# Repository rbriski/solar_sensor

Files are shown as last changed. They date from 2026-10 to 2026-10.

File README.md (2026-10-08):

# Solar roof temperature sensor

A solar-powered **Seeed XIAO ESP32-C6** reads a waterproof DS18B20 probe, sends a reading over Wi-Fi, then sleeps. A separate Linux receiver stores readings and serves a live dashboard. This repository contains the wiring, firmware, receiver, perfboard layout and printable enclosure needed to reproduce the build.

The original unit is assembled and mounted. The current tray and probe arm have been physically fitted. Outdoor lifetime, sealing and battery endurance depend on the installation; the printed enclosure has no certified IP rating.

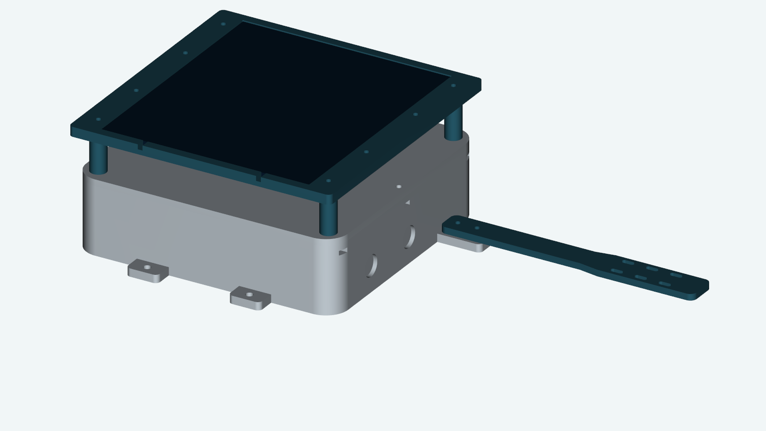
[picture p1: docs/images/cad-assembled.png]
Assembled enclosure and solar panel


## How it works

```mermaid
flowchart LR
    Panel[5 V solar panel] --> Manager[DFRobot DFR0559]
    Battery[Single-cell lithium battery] <--> Manager
    Manager -->|USB power| C6[XIAO ESP32-C6]
    Probe[DS18B20 probe] -->|D2| C6
    C6 -->|Wi-Fi / authenticated HTTPS| Receiver[Linux receiver]
    Receiver --> DB[(SQLite)]
    Receiver --> Dashboard[Private live dashboard]
    Receiver -. optional MQTT .-> Consumer[Pi or other consumer]
```

The sensor can use an isolated device Wi-Fi network. Tailscale Funnel gives it an HTTPS route to the receiver without joining the tailnet. The receiver can run on a DGX, spare Linux computer or server; a Pi or pool controller can consume its data independently. The sensor does not depend on chlorination, flow-control software or a running Pi.

Default firmware sleeps for **300 seconds**, with at most 20 seconds awake per cycle. It verifies TLS and requires an acknowledgement after the receiver saves the event. Network failures lead to sleep and a fresh reading next wake; the node does not buffer missed readings. Retried events keep their original receipt time.

## Build it in this order

| Step | Guide | Completion check |
| --- | --- | --- |
| 1 | [Parts and tools](docs/parts.md) | Correct C6, power manager and measured component sizes |
| 2 | [Breadboard wiring](docs/wiring.md) and [USB probe firmware](docs/firmware.md#1-test-the-probe-over-usb) | A valid temperature changes when you warm the probe |
| 3 | [Receiver setup](monitor/README.md) and [wireless firmware](docs/firmware.md#2-build-the-wireless-firmware) | A new reading appears on the dashboard |
| 4 | [Battery and solar power](docs/wiring.md#battery-and-solar-power) | Readings continue on solar-manager USB power |
| 5 | [Perfboard layout](docs/perfboard/README.md) | Continuity and powered voltage checks pass |
| 6 | [Print and assemble](hardware/enclosure/README.md) | Parts fit, cables seal and readings continue after closing |
| 7 | Choose a mount for your location | Probe position, radio reception and attachment suit the site |

The [full schematic](docs/perfboard/full-schematic.svg) and perfboard views render on GitHub. Download the [complete Bambu X2D project](hardware/enclosure/bambu/solar-enclosure-X2D.3mf) or use the [STEP/STL models](hardware/enclosure/models) for another printer.

**Optional battery voltage:** the divider works while the C6 is powered, but is not automatically isolated when that power disappears. Leave its jumper open for the basic unattended build. Read the [battery-sense limits](docs/wiring.md#optional-battery-voltage) before adding it. Voltage is not a calibrated charge percentage.

## Find your way around

- [Troubleshooting](docs/troubleshooting.md): temperature, power and HTTPS faults.
- [Reproducing and changing the project](CONTRIBUTING.md): AI-agent starting prompt, source files and checks.
- [Optional mounting example](hardware/mount-example/README.md): a clamp mount for one roof structure. Another mount can use the enclosure's external ears.
- `firmware/`: USB test and sleeping Wi-Fi node; local credentials are ignored.
- `monitor/`: receiver, dashboard, transport checks and systemd installer.
- `hardware/enclosure/`: current CAD, models, settings and assembly instructions.

Start with the C6 build as documented. A different board, battery, adapter, perfboard hole pattern or panel can require wiring and CAD changes. Confirm differences before printing or soldering.

## License

The original code, documentation and CAD designs are available under the [MIT License](LICENSE), copyright © 2026 Bob Briski. Bundled third-party material retains its own terms; see [third-party notices](THIRD_PARTY_NOTICES.md).

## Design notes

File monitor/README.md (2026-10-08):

# Linux receiver and dashboard

[Build overview](../README.md) · [Firmware next](../docs/firmware.md)

The receiver accepts token-authenticated HTTPS readings through **Tailscale Funnel**, saves them in SQLite, then acknowledges the event ID. It writes a dashboard snapshot every two seconds. A Pi or another consumer can read the receiver's data independently; MQTT is optional.

This setup needs Linux with systemd user services, Python 3.10+, and [Tailscale](https://tailscale.com/download/linux) signed in to your tailnet. Use an always-on receiver. The ESP32 does **not** run Tailscale: it reaches the public Funnel hostname from ordinary Wi-Fi. That network must allow DNS, NTP and the selected HTTPS port.

## 1. Install the receiver

Clone the repository to a permanent directory and run from its root:

```bash
python3 -m venv .venv
.venv/bin/python -m pip install -r monitor/requirements.txt
.venv/bin/python monitor/install.py --public-url 'https://YOUR-RECEIVER.YOUR-TAILNET.ts.net:10000/solar-roof/ingest'
```

Replace the example hostname with this receiver's full Tailscale DNS name, visible in `tailscale status --json` under `Self.DNSName` (omit its final dot). Enable HTTPS certificates and Funnel for the node as required by your tailnet policy. The [Funnel setup guide](https://tailscale.com/docs/features/tailscale-funnel) describes those prerequisites.

The installer creates:

| Path | Contents |
| --- | --- |
| `~/.config/solar-sensor/collector.json` | Private token and receiver settings, mode 0600 |
| `~/.config/solar-sensor/transport-watchdog.env` | Public URL, snapshot path, recovery setting, mode 0600 |
| `~/.local/share/solar-sensor/readings.sqlite3` | Durable readings, created when the receiver runs |
| `~/.local/share/solar-sensor/public/` | Dashboard, latest JSON and public transport summary |
| `~/.config/systemd/user/solar-sensor-*` | User units with your actual repository/Python paths |

It generates a random `ingest_token` and **keeps existing credentials, data paths and recovery settings on reinstall**. Open `collector.json` locally to copy the token into the firmware's ignored `secrets.h`. Do not paste it into issue reports. Only HTML, JavaScript and public summaries belong in the `public` directory; keep the private config and database outside it.

The installer does not start services or change Tailscale. Run:

```bash
systemctl --user daemon-reload
systemctl --user enable --now solar-sensor-collector.service
systemctl --user status solar-sensor-collector.service --no-pager
sudo loginctl enable-linger "$USER"
```

Lingering lets the user services run after logout and start at boot. Keep the repository and virtual environment at their installed paths; rerun the installer if moving them.

## 2. Route public ingestion and private viewing

First inspect existing routes with `tailscale serve status` and `tailscale funnel status`. The example uses **10000 for public ingestion** and **8443 for private viewing**; choose unused ports if the receiver already hosts other services.

```bash
tailscale funnel --bg --https=10000 --set-path=/solar-roof http://127.0.0.1:8790
tailscale serve --bg --https=8443 http://127.0.0.1:8791
```

If Tailscale requires administrative permission, use your established operator account or run those configuration commands with `sudo`. Funnel supports ports 443, 8443 and 10000; its [CLI reference](https://tailscale.com/docs/reference/tailscale-cli/funnel) explains persistent `--bg` routes. **Keep the dashboard on a different port:** Funnel makes a host/port public, so another path on the same port is not a private dashboard.

The ingest server binds only to loopback and serves POST `/ingest` or `/solar-roof/ingest`; it does not serve files. The optional dashboard server binds to loopback on 8791. Default URLs:

```text
Sensor URL:  https://YOUR-RECEIVER.YOUR-TAILNET.ts.net:10000/solar-roof/ingest
Dashboard:   https://YOUR-RECEIVER.YOUR-TAILNET.ts.net:8443/
Data feed:   https://YOUR-RECEIVER.YOUR-TAILNET.ts.net:8443/latest.json
```

Check the public ingest route without a token. **401 Unauthorized is the expected healthy response**:

```bash
curl --silent --show-error --output /dev/null --write-out '%{http_code}\n' --request POST 'https://YOUR-RECEIVER.YOUR-TAILNET.ts.net:10000/solar-roof/ingest'
```

A browser GET returns 404 by design. View the dashboard from a tailnet-connected browser. After [uploading firmware](../docs/firmware.md), check the receipt time advances and persists after restarting the collector. Retransmission of the same event must not make an old reading look new.

## 3. Monitor transport health

```bash
systemctl --user enable --now solar-sensor-transport.timer
systemctl --user start solar-sensor-transport.service
journalctl --user -u solar-sensor-transport.service -n 20 --no-pager
```

The watchdog checks local ingestion, public DNS, Funnel routing and TLS through each public IPv4 address. It checks public DNS separately from MagicDNS so a healthy tailnet-only route cannot mask a broken public route. It combines transport results with reading age. A healthy route with an overdue sensor is a sensor/power problem, not a reason to reconnect Tailscale.

Automatic recovery defaults **off** for new installs. To enable it, allow the service user to operate Tailscale (for example, `sudo tailscale set --operator="$USER"` if appropriate for this host) and change this line in the private environment file:

```text
SOLAR_FUNNEL_AUTO_RECOVERY=1
```

The next timer run reads it. Recovery requires three consecutive qualifying failures, stale sensor data, a healthy local collector, two successful public DNS checks and failed public network/TLS transport. It excludes certificate-validation errors and ordinary HTTP authorization errors. It allows one reconnect per incident with a one-hour cooldown, and rearms after five healthy checks.

The recovery service briefly runs `tailscale down` then `tailscale up`; this affects **all Tailscale connections on that receiver**. It records a persistent recovery marker, checks preferences/routes afterward and includes an `ExecStopPost` recovery path. It does not reset Funnel configuration. Set the variable back to `0` to disable automatic reconnects while keeping monitoring. Existing installations retain their current opt-in on reinstall.

## Optional MQTT consumers

No broker is required for HTTPS ingestion or the dashboard. To relay readings, add these keys to the private collector config and restart its service:

```json
{
  "mqtt_enabled": true,
  "host": "127.0.0.1",
  "port": 1883,
  "username": "YOUR_BROKER_USER",
  "password": "YOUR_BROKER_PASSWORD"
}
```

These are additional keys, not a replacement for the full config. Use a local or appropriately secured broker; this example uses plain MQTT on loopback. Fresh events are relayed to `pool/solar-roof/temperature`, QoS 1, retained. The receiver also accepts legacy non-retained readings on that topic and acknowledges them on `pool/solar-roof/ack`. Retained MQTT messages are never treated as newly received samples.

MQTT failure does not prevent an HTTPS reading from being saved or acknowledged. MQTT relay is best effort, with no durable forwarding queue. Consumers needing a complete history should read SQLite or the receiver's snapshot instead of treating broker delivery as the system of record.

## Data and maintenance

`latest.json` contains `generated_at`, total `count`, `latest` and the latest 240 events in `history`, oldest first. Each event has receiver-generated `received_at`, the node's unique `event_id`, temperatures/status, Wi-Fi signal and sleep interval. Invalid probe temperatures and disabled/invalid battery voltage are null. Freshness uses receipt time, not value changes; a duplicate preserves its original timestamp.

SQLite table `readings` contains `event_id TEXT PRIMARY KEY`, `received_at REAL`, and the original JSON `payload`. The database keeps all events. Back it up with SQLite's backup command rather than copying a live database without its WAL:

```bash
sqlite3 "$HOME/.local/share/solar-sensor/readings.sqlite3" ".backup '/path/to/backup/readings.sqlite3'"
journalctl --user -u solar-sensor-collector.service -n 30 --no-pager
systemctl --user list-timers solar-sensor-transport.timer --no-pager
```

The dashboard keeps updating while the sensor sleeps; an overdue reading turns its status red. See [troubleshooting](../docs/troubleshooting.md) for power, probe and transport diagnosis. This receiver currently handles one sensor identity, `roof-solar-reference`; adding multiple nodes requires changes to identity validation and per-sensor dashboard storage/querying.

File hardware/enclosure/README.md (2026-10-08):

# Enclosure, printing and assembly

[Project overview](../../README.md) · [Parts](../../docs/parts.md) · [Optional mount](../mount-example/README.md)

This is the **current fitted set**: original body/lid/frame geometry, corrected four-corner perfboard tray and paired-slot probe arm. The full project contains these parts together. Old trays, edge clips and perpendicular-slot arms are no longer alternatives to choose between.

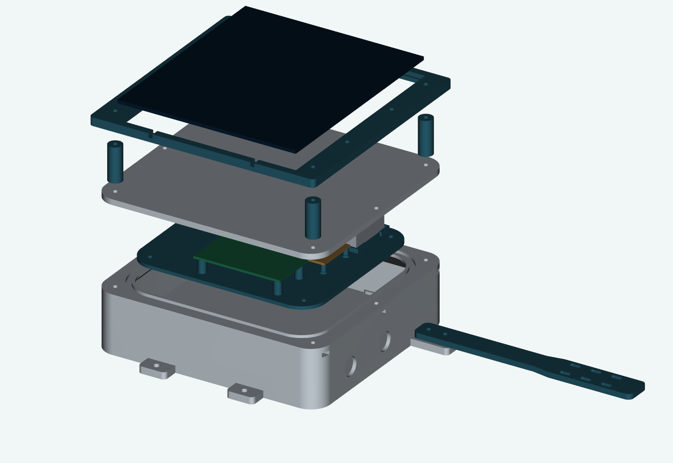
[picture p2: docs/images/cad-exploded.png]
Exploded assembly


## Files to print

Download [solar-enclosure-X2D.3mf](bambu/solar-enclosure-X2D.3mf) with GitHub's **Download raw file** button and open it in Bambu Studio. It contains **13 objects on four plates** with saved X2D printer, process and filament settings. Check the selected printer, nozzle and plate before sending a print.

| Plate | Parts | Quantity |
| --- | --- | --- |
| 1 | [Base](models/base.stl) | 1 |
| 2 | [Lid](models/lid.stl), [25 mm panel spacers](models/panel_spacer.stl) | 1 + 4 |
| 3 | [Solar panel frame](models/panel_frame.stl) | 1 |
| 4 | [Tray](models/tray.stl), [panel clips](models/panel_clip.stl), [probe arm](models/probe_arm.stl) | 1 + 4 + 1 |

All parts have editable STEP companions in [models](models). `assembly-reference.step` includes non-printable component envelopes for clearance checks; do not slice the whole reference assembly.

The saved settings use **Bambu X2D, standard 0.4 mm nozzle, Textured PEI**, white PETG at **240 °C**, bed **80 °C first layer / 75 °C thereafter**, 0.20 mm layers, 6 walls, 6 top/bottom layers, 25% gyroid, no supports and a 6 mm outer brim. Outer walls are 45 mm/s and volumetric flow is capped at 8 mm³/s. These follow the original filament label; adjust for a different material or calibrated printer.

The project is sliced and reopened with Bambu Studio 2.8.2.61 CLI. Its [validation record](bambu/project-validation.json) records settings, mesh checks and estimates. Plate thumbnails are rendered from the actual CAD because offscreen native thumbnails were unavailable. GUI interaction, seal performance and hot-weather strength are not certified by those checks.

## Dimensions that must match your parts

| Item | Modeled fit |
| --- | --- |
| Body | 164 × 152 × 42 mm, excluding external mounting ears; 2.4 mm walls, 3 mm floor |
| Solar panel | 130 × 150 × 2.5 mm; 130.8 × 150.8 mm pocket, central wire clearance |
| Battery | Actual measured pack 54 × 33 × 10 mm |
| Perfboard | 70 × 30 mm; **66 × 26 mm hole centers**; 1.5 mm board, 10 mm components above and 1 mm solder below |
| DFR0559 | 63 × 33 mm; **55 × 25 mm hole centers**; 1.6 mm board, 9 mm components above and 1 mm below |
| Cable bend allowance | 45 mm beyond the manager board's USB end |
| Glands | Two PG7 holes, 13.2 mm diameter through 2.4 mm wall |
| O-ring | AS568-164 EPDM 70A, 158.42 mm ID × 2.62 mm cross section |
| Groove | 3.8 mm wide, 2 mm deep; rounded rectangle, 144 × 132 mm centerline, 22 mm corner radius |
| External mounting ears | Four 4.5 mm holes on 64 × 164 mm centers |

Different generic perfboards often have different mounting holes even if both are sold as “3 × 7 cm.” Measure centers before printing. The current perfboard posts replace the earlier incorrect mount; the DFRobot and battery locations remain fitted.

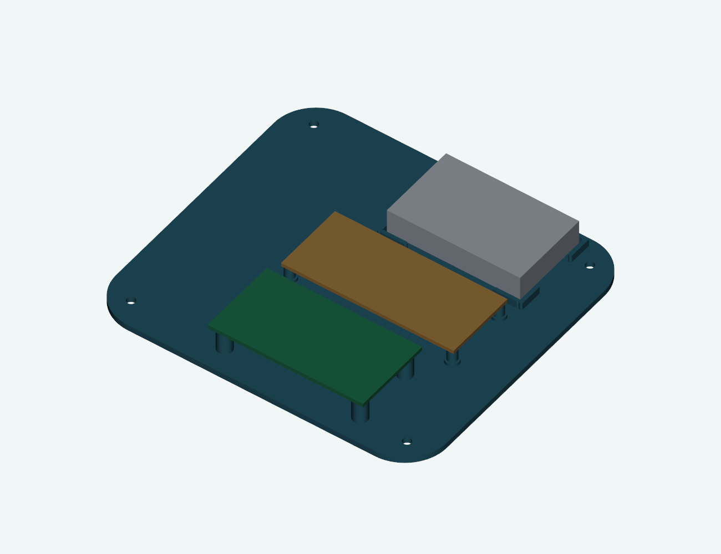
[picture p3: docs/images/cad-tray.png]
Tray with board and battery envelopes


Current perfboard mounting dimensions

## Fasteners

Lengths are measured **under the head**, including a pointed self-tapping screw's tip. Use small pan or button heads where they clear the components. Drive printed-plastic screws by hand. Self-tapping means they cut/form threads in the printed pilot; **self-drilling screws are not intended**.

| Quantity | Fastener | Joint | Type |
| --- | --- | --- | --- |
| 4 | **M1.7 × 6 mm** | C6 **perfboard** to tray posts | **Self-tapping for plastic**, no washer in the calculated stack |
| 4 | **M3 × 5 mm** | DFRobot to raised tray posts | **Self-tapping for plastic**, no washer in the calculated stack |
| 4 | **M3 × 6 mm** | Tray to body posts | **Self-tapping for plastic**, no washer in the calculated stack |
| 4 | **M3 × 45 mm** | Frame → spacer → lid → body corner nut | **Machine screw** + flat washer |
| 2 | **M3 × 12 mm** | Two middle side lid holes → body nuts | **Machine screw** + flat washer |
| 4 | **M3 × 10 mm** | Four panel retaining clips → frame nuts | **Machine screw** + flat washer |
| 2, optional | **M3 × 10 mm** | Probe arm → body bracket nuts | **Machine screw** + flat washer |
| 12, or 10 without arm | Ordinary M3 hex nuts | Six body closure pockets, four clip pockets, two arm pockets | Not nylon locknuts; pockets assume about 5.5 mm across flats / 2.4 mm thickness |
| 12, or 10 without arm | M3 flat washers, about 0.5 mm thick | Machine-screw joints above | Do not add to board/tray stacks without recalculating |

The original builder recalled **M1.7 self-tapping for the C6/perfboard** and **M3 self-tapping for DFRobot and tray**. The lengths above are derived from the CAD, not a guess at the installed screws:

| Joint | Material under screw head | Blind pilot depth | Screw insertion including point | Remaining tip clearance |
| --- | --- | --- | --- | --- |
| Perfboard, 6 mm screw | 1.5 mm board | 5.3 mm, Ø1.3 mm | 4.5 mm | **0.8 mm** |
| DFRobot, 5 mm screw | 1.6 mm board | 5.0 mm, Ø2.6 mm | 3.4 mm | **1.6 mm** |
| Tray, 6 mm screw | 2.4 mm tray | 4.0 mm, Ø2.6 mm | 3.6 mm | **0.4 mm** |

**The tray clearance is tight.** Check actual screw length, print thickness and pilot depth before tightening. A screw must clamp the part before its tip bottoms out. Self-tapping thread profiles vary; nominal diameter alone does not prove pilot compatibility. Check one post by hand, stop if the post cracks or the screw bottoms, and avoid an oversized head touching circuitry. The C6 itself is soldered to the perfboard; these four small screws secure the perfboard, not the C6 module.

## Assembly sequence

1. Remove brims and strings. Dry-fit gland nuts, ordinary M3 nuts and boards. Inspect screw pilots without enlarging them indiscriminately. Keep batteries away from tools and loose screws.
2. Install two glands with their supplied wall seals. Use **one round cable per gland**: probe and panel separately. Two cables under one ordinary round seal leave a potential leak path. Pass cables through before termination and make external drip loops.
3. Fasten DFRobot and perfboard to the tray using their self-tapping screws. Keep solder protrusions within the modeled 1 mm underside clearance. Strap the battery softly in its cradle; do not puncture or compress it.
4. Fit the tray with four M3 × 6 self-tapping screws. Route the short USB cable in its bend space; secure wiring away from lid, O-ring and fasteners. Complete the [power and reading checks](../../docs/perfboard/README.md#checks-before-power).
5. Fit the panel in the frame, rear toward the enclosure. Slide the **four panel clips** over its inactive edge and fasten with M3 × 10 machine screws and nuts. The frame ledge supports the panel; the clips keep it from lifting. They are not clamps for crushing the panel. Allow its rear wires to bend without pinching.
6. Fit the probe arm, if used, with two M3 × 10 machine screws and nuts. Pass ties through the paired longitudinal slots, around the probe and back through the matching slot. Keep the sensing end exposed and away from direct contact with the warm enclosure.
7. Lay the O-ring evenly in the clean lid groove. Install the lid, four 25 mm spacers and panel frame. The four **M3 × 45** screws pass through frame and spacers, through the lid and into ordinary nuts captured in the body. The two **M3 × 12** screws close the remaining middle side holes. Tighten evenly; stop when seated rather than distorting the lid.
8. Confirm a new remote reading after closing. Check seals with the electronics and battery removed before relying on the case outdoors; dry completely afterward. Monitor internal temperature against the battery maker's charge-temperature limit, especially in sun. A white case and panel shade do not guarantee safe battery temperature.

Panel retention and lid connection

Probe ties through paired slots

Probe placement depends on what you want to measure. This exposed probe is a solar reference, not a shielded meteorological air-temperature sensor. Keep its sensing end outside enclosure/panel shadow and avoid touching the case or mounting hardware. Compare positions at your site; there is no universal minimum cable distance. A different mount can attach to the external ears without opening the sealed volume.

## Rebuild the design

See [development commands](../../CONTRIBUTING.md#cad-and-print-project). `build_enclosure.py` exports current solids, meshes and clearance/fastener checks. Edit the relevant geometry functions for substitutions, regenerate, inspect fit and regenerate the print project together. The exported `parameters.json` describes dimensions; editing it alone does not change CAD.

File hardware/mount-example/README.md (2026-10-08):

# Optional clamp-mount example

[Enclosure](../enclosure/README.md) · [Project overview](../../README.md)

This is one installed solution for a particular existing roof collector structure. It attaches to dry rigid support tubes using lined saddles and worm-drive clamps, without changing the assembled enclosure. Treat it as a worked example for adapting the enclosure's external ears, not a universal shingle attachment.

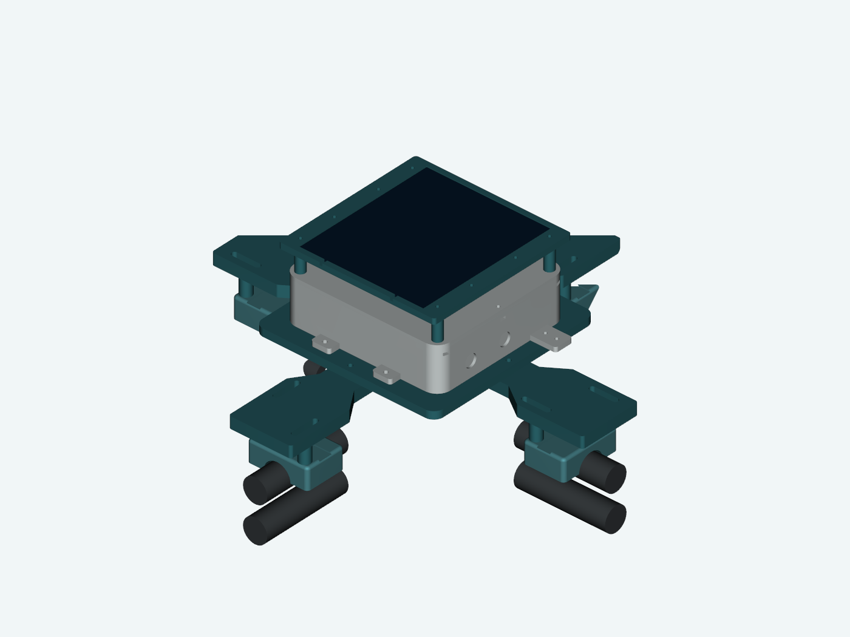
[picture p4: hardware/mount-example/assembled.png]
Example assembled clamp mount


The original measurements were approximately 25.4 mm tube diameter, 12.7 mm clear vertical gap between tubes, 73 mm square openings and 305 mm between opposite opening centers. Slots allow approximately 281–329 mm opposite spacing. The carrier accepts the enclosure's four holes on **64 × 164 mm centers**. Measure your structure and assess its condition/load capacity before reusing this design.

## Parts and fasteners

| Part | Quantity | Notes |
| --- | --- | --- |
| [Carrier](models/carrier.stl) | 1 | 190 mm square frame |
| [Arm](models/arm.stl) | 4 | 12 mm thick, slotted saddle connections |
| [Saddle](models/saddle.stl) | 4 | Current self-tapping version; 3.5 mm pilots, 20 mm blind depth |
| [20 mm spacer](models/spacer-20.stl) | 8 | 4.5 mm bore, 12 mm outside diameter |
| M4 × 20 mm machine screw | 4 | Enclosure ears to carrier; M4 washers and nylon locknuts |
| M4 × 25 mm machine screw | 8 | Arms to carrier; M4 washers and nylon locknuts |
| **#8 × 2 inch self-tapping screw** | 8 | Stainless pan head; fits existing spacers and arm slots |
| Large washers, approximately 12 mm OD, 1 mm thick | 8 | Under #8 screw heads, covering 6 mm slots |
| Stainless worm-drive clamps, 40–60 mm range, 9 mm band | 4 | One around each upper tube and saddle; head must fit the 14 mm channel |
| 1 mm EPDM lining | 4 strips | Between saddle/clamp and tube |

The selected screw example is [Everbilt #8 × 2 inch stainless pan-head self-tapping, model 807872](https://www.homedepot.com/p/204283146). A 50.8 mm screw through a 1 mm washer, 12 mm arm and 20 mm spacer enters the saddle by **17.8 mm**, leaving **2.2 mm** before the blind pilot floor. This includes the pointed tip, not all full-depth threads. Check actual screw and washer dimensions.

Use [replacement-saddles-X2D.3mf](replacement-saddles-X2D.3mf) for **four saddles only**, configured for the same white PETG/X2D setup as the enclosure. Its [mesh validation](project-validation.json) confirms the current saddle geometry. It does not contain carrier, arms or spacers; their current STEP/STL files are in [models](models). The supplied saddle STL is already rotated onto its axial end for printing. Do not print the assembly-reference meshes as extra parts.

## Installation order

1. Line and place each saddle over its **upper dry support tube**. Thread one worm clamp under that tube and through the saddle's crown channel. Do not wrap both tubes together. Tighten only enough to retain the saddle without damaging aged plastic.
2. Attach the four arms to the carrier, then the assembled enclosure to the carrier using the M4 machine screws and locknuts.
3. Set the assembly on the eight spacers. Insert #8 screws from above, through washers, arm slots and spacers into the saddle pilots. The spacers must be free clearance around the screws. Hand-tighten evenly; no inaccessible locknut is required below a saddle.
4. Check that neither screws nor clamps touch the lower tubes or roof, cables have slack and drip loops, the panel/probe have the intended exposure, and new readings still arrive.

Clamp routing

Self-tapping saddle stack

`build_mount.py` reproduces the current geometry using the enclosure's CAD helpers. The original unit is mounted, but there is no measured wind rating, hot-weather creep life or pull-out rating. Do not attach blindly to shingles, plumbing or an unknown roof component; choose and verify an attachment appropriate to the actual site.

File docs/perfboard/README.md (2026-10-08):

# Perfboard assembly

[Breadboard first](../wiring.md) · [Enclosure next](../../hardware/enclosure/README.md)

Use **30 × 70 mm isolated-pad board**, 10 columns across the short side and 24 rows along the long side. Numbers **1–10** run across; letters **A–X** run along. USB faces row A. These are hole coordinates, not GPIO numbers: hole **D2** happens to carry C6 signal **D2**, while A0 is at **B2**.

Full schematic

## Component side: insulated wires

Component side, USB at top

All solid top runs are **insulated wires connecting their two ends**. A bend over another pad is not a solder joint. The C6 header rows occupy B2–H2 and B8–H8. Its B8/5V pad is unused.

| Part | Holes | Detail |
| --- | --- | --- |
| R3, 4.7 kΩ | L2–L6 | Probe DATA pull-up to 3V3; omit the breadboard adapter |
| R1, 100 kΩ | P3–T3 | Optional BAT+ sense resistor |
| R2, 100 kΩ | P5–T5 | Optional sense-to-ground resistor |
| C1, 100 nF | P7–R7 | Optional sense filter; nonpolar |
| J1, two-pin header | V3–V4 | Optional removable sense shunt; leave open initially |
| TB1, 3-position terminal | W7, W8, W9 | **DATA, 3V3, GND**, respectively; cable openings face row X |
| BAT+ sense lead | X3 | Optional, from manager BAT IN +; not the main battery power lead |

| Insulated wire | Endpoints | Signal |
| --- | --- | --- |
| W1 | B1 → O3 | A0 sense, optional |
| W2 | D1 → K2 | DATA, kept clear of D3–D6 headers |
| W3 | D9 → K6 | 3V3 |
| W4 | L1 → U7 | DATA to terminal block |
| W5 | L7 → U8 | 3V3 to terminal block |

Keep enough clearance around USB and terminal screws. The 2.54 mm block fits this layout; a wider-pitch block needs a new layout.

## Solder side: bare bridges and shared ground

Solder side, mirrored with USB at top

This view is **mirrored left to right**, with USB still at the top. Columns now read 10–1. Do not turn the drawing upside down. Bare runs deliberately join intermediate pads on their listed paths; inspect them for accidental contact with adjacent pads.

| Run | Path |
| --- | --- |
| G0 | C8 → C10 → T10, shared ground rail |
| G1 | L9 → L10, spare ground landing |
| G2 | R7 → R10, capacitor ground |
| G3 | T5 → T10, resistor ground |
| G4 | T10 → W10 → W9, terminal ground |
| S1 | B1 → B2 |
| S2 | D1 → D2 |
| S3 | D8 → D9 |
| S5 | K2 → L2 → L1 |
| S6 | K6 → L6 → L7 |
| S9 | O3 → P3 |
| S10 | P3 → P7, including P5 |
| S12 | V4 → T4 → T3 |
| S14 | V3 → X3 |
| S15 | U7 → W7 |
| S16 | U8 → W8 |

For a temperature-only build omit R1, R2, C1, J1, the BAT+ lead, W1 and their dedicated sense/ground bridges. Keep the shared ground rail, probe pull-up and terminal wiring. If populating the full board, retain the [battery-sense power-off precautions](../wiring.md#optional-battery-voltage).

## Soldering order

1. With every power source disconnected, mark A1 and USB direction on the board. Dry-fit the C6/header footprint, terminal and mounting holes before soldering.
2. Fit resistors and capacitor first, then headers and terminal. Tack one pin on each header/block, check alignment, then finish. Keep leads low enough for the tray clearance.
3. Add the short bare bridges, then the ground rail, then the five insulated top wires. Solder wire ends; never strip an entire top run just to join two points.
4. Fit the C6 and inspect both sides under magnification. Avoid solder spikes below the board. Leave J1 open.
5. Feed the probe through its gland before terminating it. Clamp each stripped stranded wire securely; do not tin the portion under a screw terminal. Gently pull each lead to check retention. Glands provide cable strain relief.

## Checks before power

| Check | Expected result |
| --- | --- |
| C6 GND → W9 | Continuity |
| C6 3V3 → W8 | Continuity |
| C6 D2 → W7 | Continuity |
| DATA → 3V3 | About 4.7 kΩ, not a short |
| 3V3 → GND; DATA → GND | No persistent near-zero short |
| Unused C6 header pads → neighboring bare runs | No unintended bridge |
| A0 → P3/P5/P7, when fitted | Continuity |
| J1 removed: X3 → divider BAT input | Open across the jumper |
| Divider resistors, when fitted | About 100 kΩ each; circuit paths can affect in-place measurement |

With J1 open, power through USB and measure about **3.3 V at 3V3** relative to C6 GND. A battery voltage such as 3.8 V on 3V3 would be wrong. Confirm a valid new temperature remotely. Test optional sensing separately using the breadboard procedure. Disconnect power before mounting; repeat delivery checks after enclosing.

The drawings come from [render_layout.py](render_layout.py). Run `python3 docs/perfboard/validate_layout.py` to check connectivity and unintended header intersections after changing the layout. [layout.json](layout.json) is generated data, not a separate design to edit.

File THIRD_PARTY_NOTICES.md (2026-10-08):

# Third-party notices

The root [MIT License](LICENSE) applies to this project's original code, documentation and CAD designs. It does not replace licenses or copyright notices attached to third-party material.

## OneWire

[`firmware/libraries/OneWire`](firmware/libraries/OneWire) is vendored from [Paul Stoffregen's OneWire repository](https://github.com/PaulStoffregen/OneWire/tree/800f26f3ee6eb446a72e013785cac3700e54cc13). Its source retains the upstream permission notices and attribution to Jim Studt, Dallas Semiconductor and other contributors. See [OneWire.cpp](firmware/libraries/OneWire/OneWire.cpp) and the [provenance record](firmware/libraries/OneWire/UPSTREAM.txt). Preserve these notices when redistributing the library.

## Bambu Studio profiles

The machine, process and filament JSON files in [`hardware/enclosure/bambu`](hardware/enclosure/bambu), and the upstream settings and machine G-code embedded in the enclosure and optional saddle 3MF projects, derive from [Bambu Studio v02.08.02.61 profiles](https://github.com/bambulab/BambuStudio/tree/v02.08.02.61/resources/profiles/BBL). Bambu Studio's [upstream license](https://github.com/bambulab/BambuStudio/blob/v02.08.02.61/LICENSE) is GNU AGPL version 3; an unchanged copy is included at [LICENSES/BambuStudio-AGPL-3.0.txt](LICENSES/BambuStudio-AGPL-3.0.txt). Those upstream portions are not relicensed under MIT.

Project-specific profile changes select the X2D, white PETG temperatures, speeds, walls, infill, brim and plate arrangement. The readable JSON files, [profile preparation script](hardware/enclosure/prepare_bambu.py) and [profile provenance](hardware/enclosure/bambu/profile-status.json) document those changes. The project's original CAD models and mesh geometry remain under MIT.

## Beads integration

The bundled Beads skill and generated integration hooks come from [Beads](https://github.com/gastownhall/beads). Its [upstream MIT license](https://github.com/gastownhall/beads/blob/main/LICENSE), copyright © 2025 Beads Contributors, is preserved at [LICENSES/Beads-MIT.txt](LICENSES/Beads-MIT.txt).

## Separately installed dependencies

Arduino/ESP32 libraries, Python packages and build tools installed by the setup instructions retain their respective licenses. The project license does not relicense those dependencies.

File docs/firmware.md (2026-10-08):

# Firmware

[Wiring](wiring.md) · [Receiver setup](../monitor/README.md)

Run commands from the repository root. Install [Arduino CLI](https://docs.arduino.cc/arduino-cli/installation/) and give your user access to USB serial devices. Tested versions:

```bash
arduino-cli core update-index --additional-urls https://espressif.github.io/arduino-esp32/package_esp32_index.json
arduino-cli core install esp32:esp32@3.3.11 --additional-urls https://espressif.github.io/arduino-esp32/package_esp32_index.json
arduino-cli lib install 'DallasTemperature@4.0.6'
arduino-cli board list
```

The URL is the [Espressif stable index](https://docs.espressif.com/projects/arduino-esp32/en/latest/installing.html). The repository includes a specific [OneWire revision](../firmware/libraries/OneWire/UPSTREAM.txt) with C6 support. **Keep `--libraries firmware/libraries`** so an older global installation does not take precedence.

Replace example port `/dev/ttyACM0` with yours. It may change after reset. Before computer USB, disconnect manager USB and open the optional battery-sense jumper.

## 1. Test the probe over USB

```bash
arduino-cli compile --fqbn esp32:esp32:XIAO_ESP32C6:CDCOnBoot=cdc --libraries firmware/libraries firmware/probe_test
arduino-cli upload --fqbn esp32:esp32:XIAO_ESP32C6:CDCOnBoot=cdc --port /dev/ttyACM0 firmware/probe_test
arduino-cli monitor --port /dev/ttyACM0 --config baudrate=115200
```

The test prints about every two seconds and expects **one DS18B20 on D2**, powered at 3V3 with its pull-up. Warm the probe to confirm a response. Close the serial monitor before another upload.

## 2. Build the wireless firmware

Complete [receiver setup](../monitor/README.md) first. Obtain its HTTPS ingest URL and private `ingest_token`, plus your device network's 2.4 GHz Wi-Fi credentials.

Create the local header only if it does not already exist, then edit it:

```bash
test -f firmware/roof_sensor/secrets.h || cp -f firmware/roof_sensor/secrets.h.example firmware/roof_sensor/secrets.h
```

Set `WIFI_SSID`, `WIFI_PASSWORD`, `INGEST_URL` and `INGEST_TOKEN`. The URL looks like:

```text
https://YOUR-RECEIVER.YOUR-TAILNET.ts.net:10000/solar-roof/ingest
```

Keep credentials out of Git, logs and AI conversations. `secrets.h` is ignored. The node uses its built-in antenna. Its Wi-Fi can be separate from the receiver network, provided DNS, NTP and HTTPS on the chosen port are reachable.

```bash
arduino-cli compile --fqbn esp32:esp32:XIAO_ESP32C6:CDCOnBoot=cdc --libraries firmware/libraries firmware/roof_sensor
arduino-cli upload --fqbn esp32:esp32:XIAO_ESP32C6:CDCOnBoot=cdc --port /dev/ttyACM0 firmware/roof_sensor
```

Each wake reads the probe, joins Wi-Fi, obtains time, verifies TLS, posts a reading and checks the acknowledged event ID. An independent 20-second deadline bounds failed wakes. Missed readings are not queued.

| Compile setting | Default | Meaning |
| --- | --- | --- |
| `ROOF_SLEEP_SECONDS` | `300` | Seconds asleep after each wake; range 1–3600 |
| `ROOF_BATTERY_SENSE` | `0` | Optional supervised divider; see [limits](wiring.md#optional-battery-voltage) |
| `ROOF_TEST_WIFI_FAILURE` | `0` | Test-only: nonexistent SSID on first wake |
| `ROOF_TEST_HTTPS_FAILURE` | `0` | Test-only: unavailable ingest path on second wake |

For a quick bench cycle, add `--build-property 'build.extra_flags=-DROOF_SLEEP_SECONDS=30'` to compilation. For supervised voltage testing, use `--build-property 'build.extra_flags=-DROOF_SLEEP_SECONDS=30 -DROOF_BATTERY_SENSE=1'`. Upload that compiled sketch. Rebuild with ordinary defaults afterward. These settings do not change firmware already on a device.

`ca_cert.h` contains public ISRG Root X1. A future certificate-authority change may require replacing this trust anchor. Do not bypass TLS verification to hide an SSL error. The node synchronizes time before checking certificates.

## 3. Verify without a computer cable

Confirm a fresh reading, then move USB to the manager using the [power procedure](wiring.md#battery-and-solar-power). Verify the receiver time advances next wake. Old dashboard values are historical data.

`temp_ok=false` and null temperatures mean the online node reported a probe error. `battery_ok=false` with null voltage is normal when sensing is off. `event_id` combines a random power-session ID and wake counter. `previous_failures`, `previous_stage` and `previous_http_status` help locate faults.

## Upload recovery

Deep sleep can remove the serial port before upload. Open J1 and use computer USB. Hold C6 **BOOT**, press/release **RESET**, then release BOOT; select the newly enumerated port and upload. Press RESET to run the application. This BOOT is separate from the DFRobot's power button.

The [firmware check script](../scripts/check_firmware.sh) compiles with dummy credentials and never uploads.

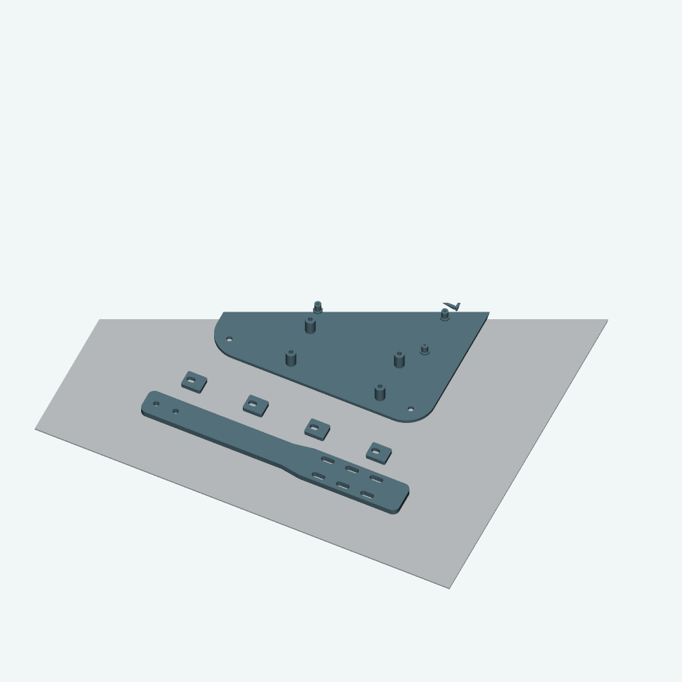
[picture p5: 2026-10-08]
docs/images/plate-4.png

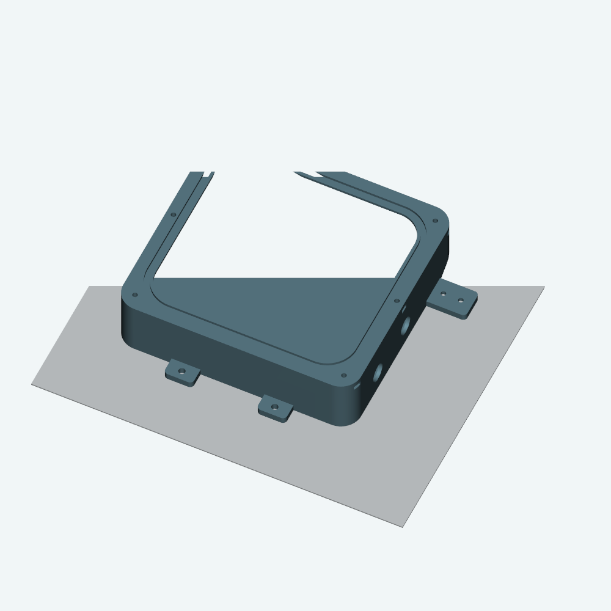
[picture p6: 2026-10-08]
docs/images/plate-1.png

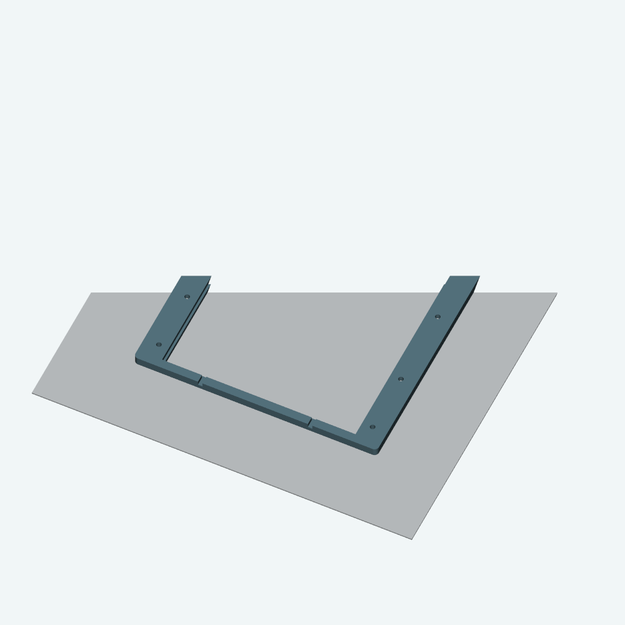
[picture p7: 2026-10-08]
docs/images/plate-3.png

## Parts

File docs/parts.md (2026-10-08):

# Parts and tools

[Overview](../README.md) · [Wiring next](wiring.md)

## Electronics

| Quantity | Part | Selection notes |
| --- | --- | --- |
| 1 | Seeed XIAO ESP32-C6 | This build uses the **C6**, with two 7-pin headers at 2.54 mm pitch. |
| 1 | Waterproof DS18B20 probe, three wires | Powered three-wire mode. Original 24 AWG stranded leads: red/power, black/ground, yellow/data; confirm your probe's assignment. |
| 1 | 4.7 kΩ resistor | Data pull-up to 3V3. A breadboard adapter may already contain it. |
| 1 | Probe screw-terminal adapter, optional | Useful for stranded leads on the breadboard. The original adapter's `472` resistor is the pull-up. |
| 1 | DFRobot Solar Power Manager 5V, **DFR0559** | Original V1.1; check labels on your version. |
| 1 | Nominal 5 V, 2.5 W solar panel | Measured **130 × 150 × 2.5 mm**, about 1 mm extra wire thickness at center. Verify compatibility with DFR0559 input limits. |
| 1 | Protected rechargeable **single-cell 3.7 V lithium battery**, 2000 mAh | Original pack marked EEMB LP103454, **measured 54 × 33 × 10 mm**. Packaging varies; check dimensions, allowed charge current and temperature limits. |
| 1 | Short USB-A to USB-C cable | Manager USB OUT to C6. Tested cable requires 45 mm beyond the DFRobot for its bend. |
| 1 | Breadboard and jumpers | Logic/probe only; charging current goes through manager connectors. |
| 1 | Isolated-pad perfboard, **30 × 70 mm** | 10 holes across × 24 along, 2.54 mm pitch. Tray assumes **66 × 26 mm mounting-hole centers**, roughly 2 mm holes. Measure yours. |
| 1 | Three-position screw terminal, **2.54 mm pitch** | Accepts the probe wire size; mounts at **W7, W8, W9**. A 5.08 mm block will not fit. |
| As needed | Insulated hookup wire and bare tinned wire | Insulated point-to-point connections on top; short bridges and shared rails underneath. |

Optional battery sensing needs **two 100 kΩ, 1% resistors; one 100 nF ceramic capacitor; one two-pin header and removable shunt**. Read the [power-off limitation](wiring.md#optional-battery-voltage) first.

The [Seeed pin table](https://wiki.seeedstudio.com/xiao_esp32c6_getting_started/) identifies D2 as GPIO2 and D0/A0 as GPIO0. Check substituted panels or cells against the [DFRobot requirements](https://wiki.dfrobot.com/dfr0559/).

## Enclosure supplies

| Quantity | Part | Fit used by the CAD |
| --- | --- | --- |
| 2 | PG7 nylon glands, seals and locknuts | Original cable range **3.1–6.6 mm**; 13.2 mm wall holes, 2.4 mm wall. Check actual gland and cable. |
| 1 | **AS568-164 O-ring**, EPDM, 70A | 158.42 mm nominal inside diameter × 2.62 mm cross section; fits the rounded rectangular lid groove. |
| 1 | White PETG filament | Original label: nozzle 225–240 °C, bed 70–80 °C. |
| 1 | Soft 10 mm hook-and-loop battery strap | Secure without compressing the pouch. |
| 2–3 | UV-resistant 2.5 mm-wide cable ties | Fit the probe arm's paired slots. |
| As needed | Stainless fasteners | Complete [size, length and type table](../hardware/enclosure/README.md#fasteners); board/tray screws are self-tapping, enclosure joints use machine screws and nuts. |

## Tools

Multimeter, temperature-controlled soldering iron, solder, flush cutters, 24 AWG wire stripper, tweezers, small manual screwdrivers, USB data cable and calipers. A Linux computer with Python 3.10+ receives data; Arduino CLI builds/uploads firmware. A printer is needed for the supplied enclosure or a custom mount.

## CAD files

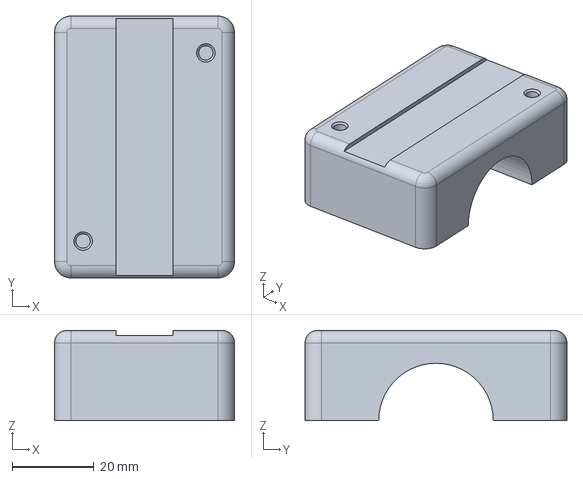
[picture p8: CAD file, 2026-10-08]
hardware/mount-example/models/saddle-assembly-reference.step
44.0 x 64.0 x 22.0 mm

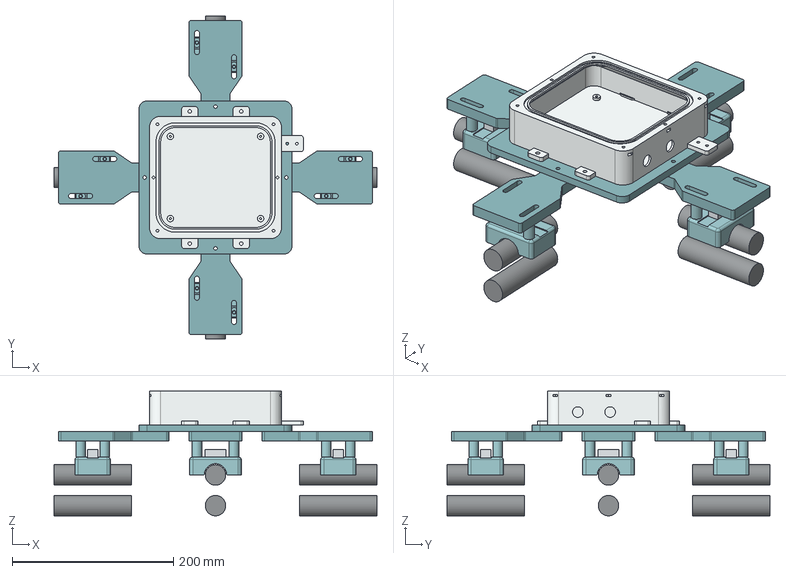
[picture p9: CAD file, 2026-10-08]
hardware/mount-example/models/mount-assembly-reference.step
400.8 x 400.8 x 154.8 mm
carrier
EXISTING_ENCLOSURE_REFERENCE
arm_0
saddle_0
UPPER_SUPPORT_REFERENCE_0
LOWER_SUPPORT_REFERENCE_0
BAND_HEAD_REFERENCE_0
spacer_0_0
spacer_0_1
arm_1
saddle_1
UPPER_SUPPORT_REFERENCE_1
LOWER_SUPPORT_REFERENCE_1
BAND_HEAD_REFERENCE_1
spacer_1_0
spacer_1_1
arm_2
saddle_2
UPPER_SUPPORT_REFERENCE_2
LOWER_SUPPORT_REFERENCE_2
BAND_HEAD_REFERENCE_2
spacer_2_0
spacer_2_1
arm_3
saddle_3
UPPER_SUPPORT_REFERENCE_3
LOWER_SUPPORT_REFERENCE_3
BAND_HEAD_REFERENCE_3
spacer_3_0
spacer_3_1

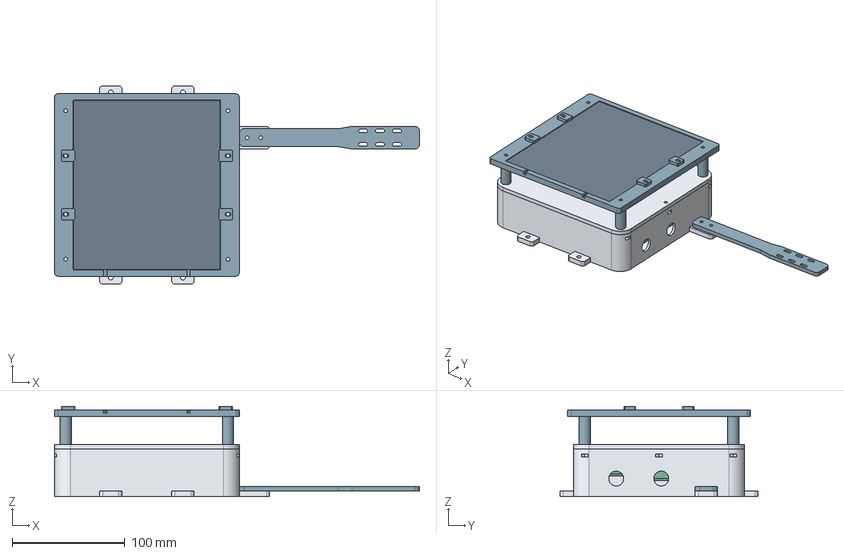
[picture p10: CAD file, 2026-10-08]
hardware/enclosure/models/assembly-reference.step
324.0 x 176.0 x 80.0 mm
base
lid
tray
panel_frame
probe_arm
panel_spacer_1
panel_spacer_2
panel_spacer_3
panel_spacer_4
panel_clip_1
panel_clip_2
panel_clip_3
panel_clip_4
solar_panel_REFERENCE
battery_REFERENCE
DFR0559_PCB_REFERENCE
DFR0559_COMPONENTS_REFERENCE
perfboard_PCB_REFERENCE
perfboard_COMPONENTS_REFERENCE

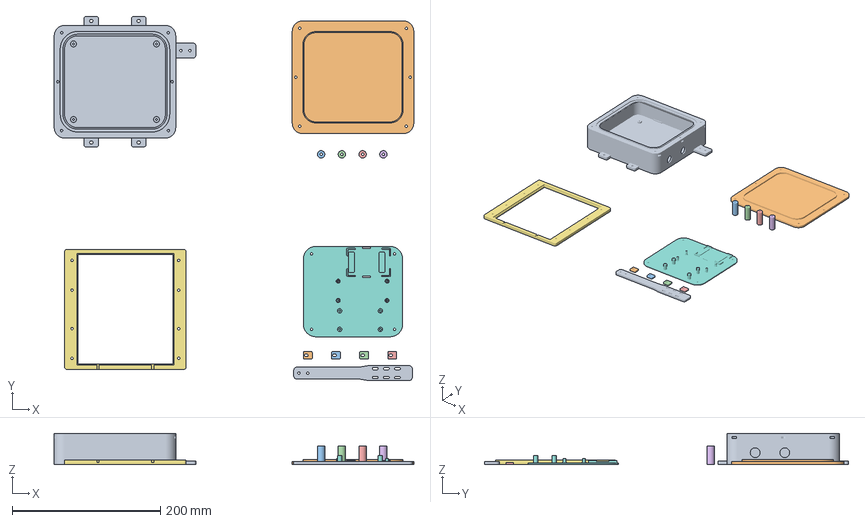
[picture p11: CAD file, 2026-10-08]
hardware/enclosure/bambu/solar-enclosure-X2D.3mf
485.2 x 491.2 x 42.0 mm
base_1
lid_1
panel_spacer_1 x 4
panel_frame_1
tray_1
probe_arm_1
panel_clip_1 x 4

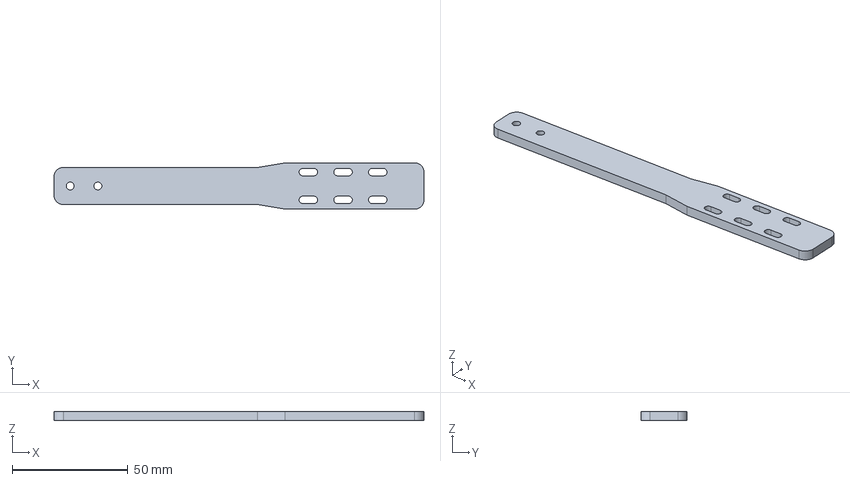
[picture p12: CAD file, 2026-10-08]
hardware/enclosure/models/probe_arm.step
160.0 x 20.0 x 4.00 mm

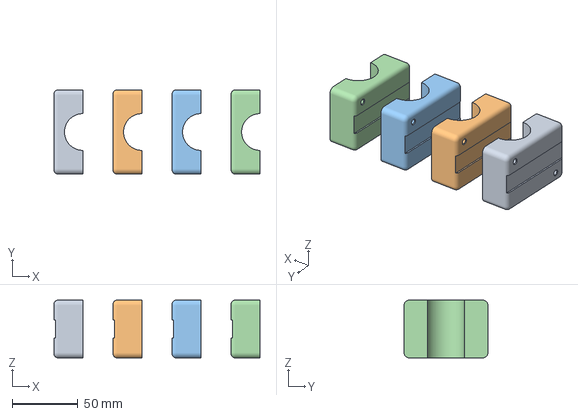
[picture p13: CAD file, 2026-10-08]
hardware/mount-example/replacement-saddles-X2D.3mf
157.0 x 64.0 x 44.0 mm
saddle-r8_1 x 4

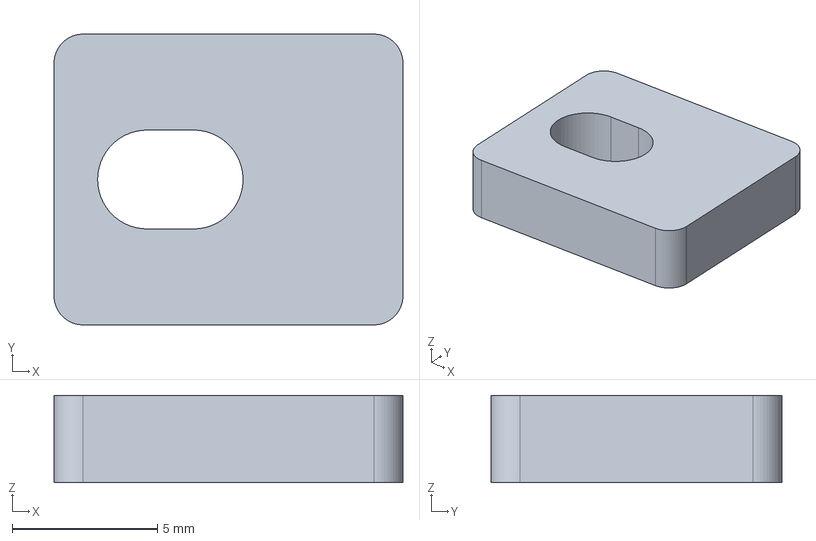
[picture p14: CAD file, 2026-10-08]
hardware/enclosure/models/panel_clip.step
12.0 x 10.0 x 3.00 mm

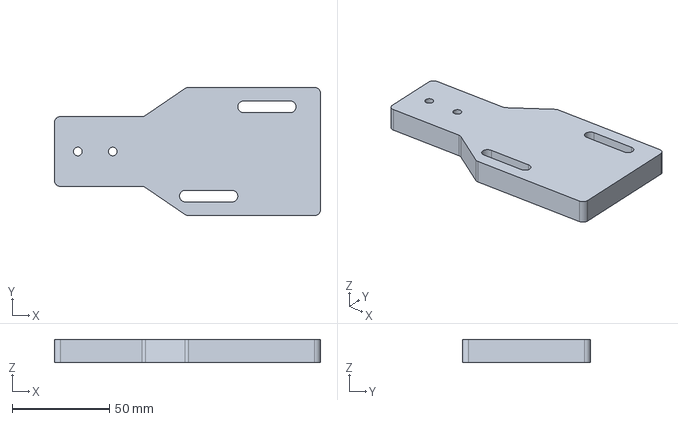
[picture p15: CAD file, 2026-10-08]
hardware/mount-example/models/arm.step
137.0 x 66.0 x 12.0 mm

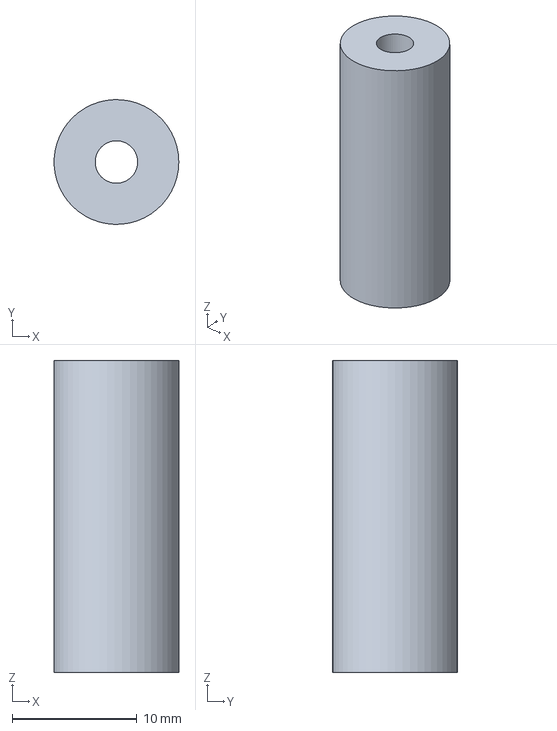
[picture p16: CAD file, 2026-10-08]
hardware/enclosure/models/panel_spacer.step
9.99 x 10.00 x 25.0 mm

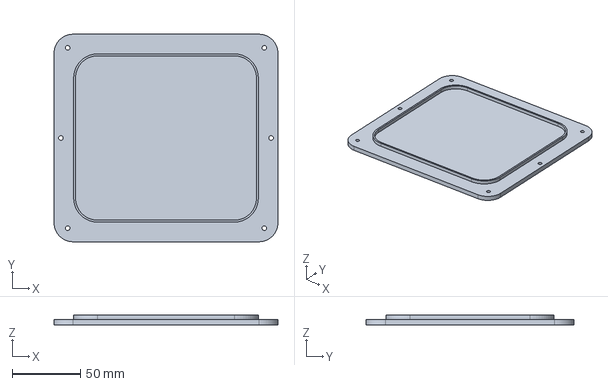
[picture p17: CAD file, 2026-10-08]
hardware/enclosure/models/lid.step
164.0 x 152.0 x 7.00 mm

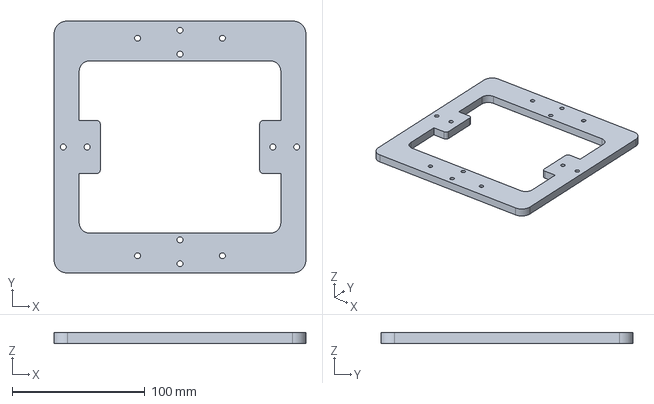
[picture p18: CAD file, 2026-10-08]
hardware/mount-example/models/carrier.step
190.0 x 190.0 x 8.00 mm

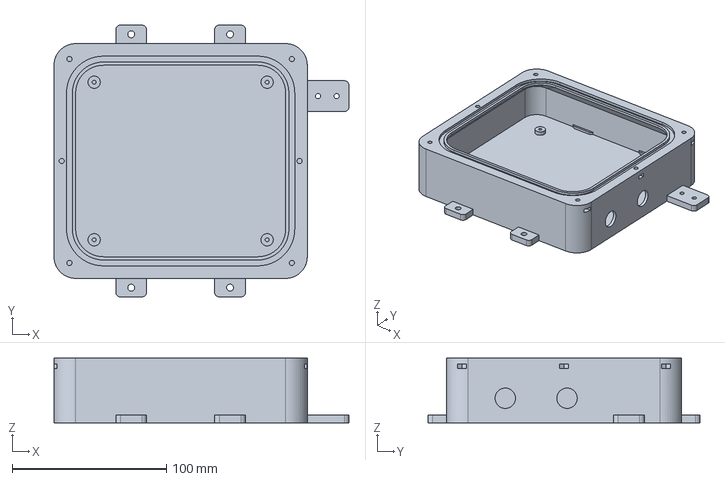
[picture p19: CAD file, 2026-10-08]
hardware/enclosure/models/base.step
191.0 x 176.0 x 42.0 mm

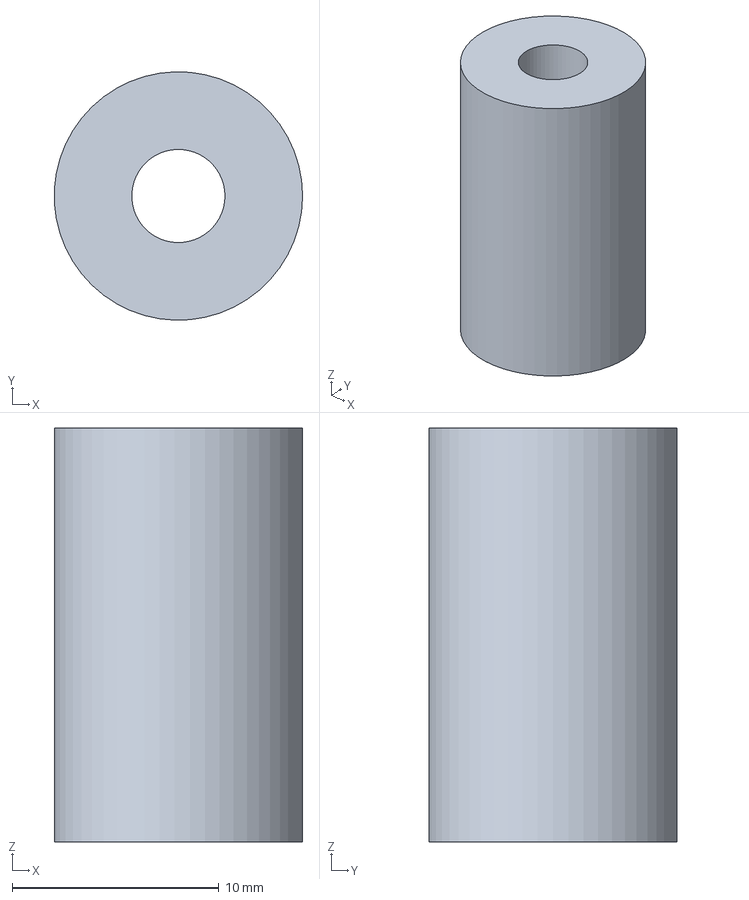
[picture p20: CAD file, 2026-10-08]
hardware/mount-example/models/spacer-20.step
12.0 x 12.0 x 20.0 mm

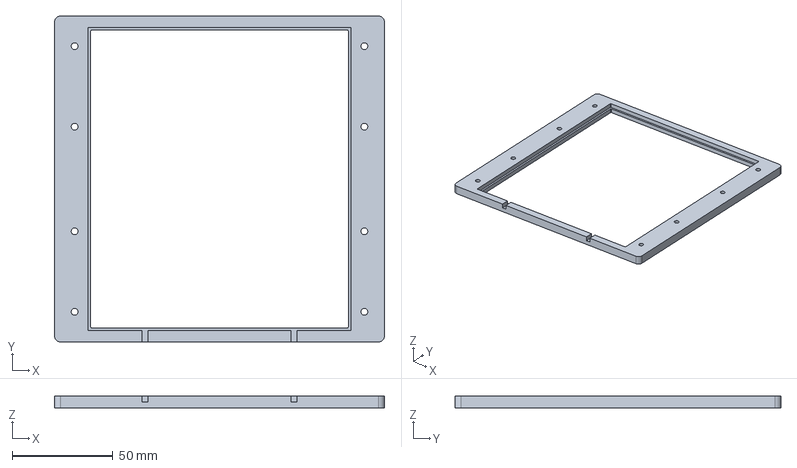
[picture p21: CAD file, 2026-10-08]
hardware/enclosure/models/panel_frame.step
164.0 x 162.0 x 6.00 mm

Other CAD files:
hardware/mount-example/models/saddle.step
hardware/enclosure/models/tray.step
hardware/enclosure/models/base.stl
hardware/enclosure/models/lid.stl
hardware/enclosure/models/panel_clip.stl
hardware/enclosure/models/panel_frame.stl
hardware/enclosure/models/panel_spacer.stl
hardware/enclosure/models/probe_arm.stl
hardware/enclosure/models/tray.stl
hardware/mount-example/models/arm.stl
hardware/mount-example/models/carrier.stl
hardware/mount-example/models/saddle.stl
hardware/mount-example/models/spacer-20.stl

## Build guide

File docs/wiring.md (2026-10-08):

# Breadboard and power wiring

[Parts](parts.md) · [Firmware](firmware.md) · [Perfboard](perfboard/README.md)

Complete electrical schematic

The drawing includes optional battery sensing. Start with the probe circuit and **leave J1 open**. Pin references are for the **XIAO ESP32-C6**: `A0`, `D0` and `GPIO0` identify the same physical pin; `D2` is GPIO2.

## Probe on USB power

Disconnect power while wiring. Put the C6 across the breadboard center gap. Check for split breadboard power rails before using them.

| From | To | Purpose |
| --- | --- | --- |
| C6 **3V3** | Probe VCC/red | Regulated probe power |
| C6 **GND** | Probe GND/black | Signal return |
| C6 **D2** | Probe DATA/yellow | OneWire data |
| 4.7 kΩ resistor | Between DATA and 3V3 | Data pull-up; no polarity |

For an adapter, use its **VCC/GND/DATA labels**, then connect those three signals to the C6. The original adapter already has a resistor marked `472` (4.7 kΩ). With power removed, measure DATA to VCC: about 4.7 kΩ means it is present. Do not add another pull-up in parallel. Loose resistors supplied with an adapter do not prove its pull-up is missing.

Before USB power, inspect for shorts and check each connection end-to-end. Power-to-ground resistance can change as capacitors charge; investigate a persistent near-zero value. Connect computer USB and run the [probe test](firmware.md#1-test-the-probe-over-usb). Confirm one sensor, valid temperature and a rise when warmed in your hand.

## Battery and solar power

Test [wireless delivery](firmware.md#2-build-the-wireless-firmware) while still on computer USB, so readings remain visible when you move the cable.

| Connection | Destination |
| --- | --- |
| Battery positive | DFR0559 **BAT IN +** |
| Battery negative | DFR0559 **BAT IN −** |
| Panel positive | DFR0559 **SOLAR IN +** |
| Panel negative | DFR0559 **SOLAR IN −** |
| DFR0559 USB OUT | C6 USB-C via short cable |

1. Keep solar disconnected and J1 open. Measure battery polarity: **red meter lead on positive, black on negative must read positive voltage**. A connector can fit with reversed polarity; the original pack connector did.
2. Connect BAT IN securely. Use screw terminals if connector polarity is wrong; never cut both live battery wires together.
3. Disconnect computer USB, then connect C6 to manager USB OUT. Keep its USB output-enable jumper fitted. If necessary press **BOOT on the DFRobot**, not BOOT on the C6.
4. Check C6 5V relative to GND is about 5 V and 3V3 is about 3.3 V. Look for a **new receipt time** on the dashboard; an old saved temperature does not prove delivery.
5. Measure panel polarity, connect SOLAR IN, and check continued delivery and indicators against the manager manual.

The [DFR0559 specification](https://wiki.dfrobot.com/dfr0559/) gives a 4.5–6 V operating solar input for a nominal 5 V panel. Check the panel's open-circuit voltage as well as its advertised operating voltage.

The C6 **5V pin and underside battery pads remain unused**. Its USB-C has one power source at a time. Direct 5V-pin power requires a separate power-path design before connecting computer USB. USB also supplies common ground for probe and divider. Do not bridge BAT IN − directly to C6 GND, which can bypass the manager's battery protection path.

## Optional battery voltage

This **manual, supervised sense circuit** is retained from the original build. It measures voltage, not an accurate remaining percentage.

```text
BAT IN + ── J1 removable jumper ── R1 100k ──┬── C6 A0 / D0
                                           ├── R2 100k ── C6 GND
                                           └── C1 100nF ── C6 GND
```

J1 is two header pins bridged by a removable shunt. It disconnects the thin sense lead, not the main battery power lead. Use a secure BAT+ connection; a terminal must reliably grip every conductor placed in it.

**Power-off limitation:** USB output can stop while the battery stays connected. With J1 closed, the divider can then feed an unpowered C6 GPIO. Software cannot disconnect that path. For an unattended reproduction, leave J1 open or omit sensing until automatic isolation has been designed and verified. `ROOF_BATTERY_SENSE=0` suppresses readings but does **not** isolate a physically connected divider.

To test on a powered bench:

1. Wire R1, R2 and C1 without power; keep J1 open. C1 is nonpolar. Check values and that BAT+ has no direct path to A0.
2. Power the C6 from manager USB. Before attaching the junction to A0, temporarily energize the divider and measure relative to **C6 GND**: junction voltage should be half BAT+. For example, 3.8 V gives about 1.9 V. Remove J1 before changing wiring.
3. Attach the verified junction to A0. With C6 powered, close J1. A 4.2 V cell gives about 2.1 V at A0.
4. Use firmware with `ROOF_BATTERY_SENSE=1`; compare reported voltage with the meter. The original one-point check was 3.882 V reported versus 3.86 V measured, not a full-range calibration.
5. **Open J1 before unplugging C6, maintenance or changing USB sources.** Close it only after power and ground are established; leave it open unattended without isolation.

The divider draws about 21 µA at 4.2 V. Firmware settles the filter, averages 32 calibrated ADC samples before Wi-Fi and multiplies by two. An unconnected A0 can float, so sensing defaults off.

## Ready for perfboard

Confirm a changing probe reading, authenticated delivery and operation on manager USB with the computer disconnected. No fixed multi-day breadboard soak is required before soldering. Repeat those functional checks after the transfer.

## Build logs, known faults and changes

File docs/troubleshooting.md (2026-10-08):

# Troubleshooting

[Build overview](../README.md) · [Receiver commands](../monitor/README.md)

Use the **last received time** and dashboard transport check together. A temperature still visible on screen may be a stored historical value. Firmware normally sleeps five minutes after each wake; the dashboard allows more than two expected cycles before declaring a reading overdue.

| Symptom | Check and next action |
| --- | --- |
| No C6 power from solar manager | Meter manager USB output and C6 5V/GND. Check USB cable, output-enable jumper, battery polarity and manager BOOT. Keep optional J1 open during power changes. |
| Reverse-battery indicator | Disconnect sources and verify BAT IN polarity with a meter. Connector fit does not prove polarity. |
| About battery voltage on C6 3V3 | Stop and recheck wiring; 3V3 should be about 3.3 V, not 3.8–4.2 V. |
| Node online, `temp_ok=false` | Power off, then check probe ground, 3V3, D2, the 4.7 kΩ pull-up and terminal grip. Firmware expects exactly one DS18B20. Run USB probe test if needed. |
| Battery voltage missing | Expected with default firmware or J1 open. Read [sense-circuit limits](wiring.md#optional-battery-voltage) before enabling. Never substitute a floating A0 value for a battery measurement. |
| Wi-Fi joins but HTTPS fails | Device Wi-Fi must permit DNS, NTP and chosen HTTPS port. Verify URL/token, public DNS and valid receiver certificate; do not disable TLS checks. |
| SSL protocol error; local collector healthy | Inspect public transport status. A Funnel relay/session fault can interrupt TLS before HTTP. The watchdog can reconnect only after its guarded conditions; it is not a cure for every SSL error. |
| Public route healthy, sensor overdue | Check device power, Wi-Fi reception and probe/firmware logs. Reconnecting healthy Tailscale will not repair an offline sensor. |
| Dashboard says collector unavailable | Check `solar-sensor-collector.service`, its journal and snapshot path. A dashboard server can still serve old files when the collector is stopped. |
| Unauthorized ingest response | A token-free health check should get 401. Firmware must use the exact private token configured on the receiver. |
| USB serial disappears | Normal during deep sleep. Use [BOOT/RESET upload recovery](firmware.md#upload-recovery). |
| Works open, fails after closing | Inspect pinched cables, shifted probe terminal wires and Wi-Fi attenuation. Verify a new receipt time after every reassembly. |

For maintenance, first open the battery sense jumper if fitted, disconnect solar and manager USB as needed, and use only one USB source for the C6. Restore power and ground before reconnecting a supervised sense circuit. Keep exposed battery leads and tools from touching each other.

Receiver recovery was added after a public HTTPS route failed while local ingestion remained healthy. It checks the actual public path, persists its incident state and bounds reconnect attempts. It cannot guarantee uninterrupted Internet access or recover a discharged battery. The receiver preserves history across restarts, while the node resumes with a fresh sample when connectivity returns.

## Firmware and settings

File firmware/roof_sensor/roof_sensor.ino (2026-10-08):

#include <WiFi.h>
#include <HTTPClient.h>
#include <NetworkClientSecure.h>
#include <time.h>
#include "ca_cert.h"
#include <OneWire.h>
#include <DallasTemperature.h>
#include <esp_sleep.h>
#include <esp_system.h>
#include <math.h>
#include "secrets.h"

#ifndef ROOF_SLEEP_SECONDS
#define ROOF_SLEEP_SECONDS 300
#endif
#ifndef ROOF_BATTERY_SENSE
#define ROOF_BATTERY_SENSE 0
#endif
#ifndef ROOF_TEST_WIFI_FAILURE
#define ROOF_TEST_WIFI_FAILURE 0
#endif
#ifndef ROOF_TEST_HTTPS_FAILURE
#define ROOF_TEST_HTTPS_FAILURE 0
#endif
static_assert(A0 == 0, "Battery divider must use D0 / GPIO0");
static_assert(D2 == 2, "Select XIAO ESP32-C6");
static_assert(ROOF_SLEEP_SECONDS >= 1 && ROOF_SLEEP_SECONDS <= 3600, "Sleep must be 1..3600 seconds");
constexpr uint32_t AWAKE_LIMIT_MS = 20000;
RTC_DATA_ATTR uint32_t bootCount = 0;
RTC_DATA_ATTR uint32_t sessionId = 0;
RTC_DATA_ATTR uint32_t failures = 0;
RTC_DATA_ATTR uint32_t previousStage = 0;
RTC_DATA_ATTR int previousHttpStatus = 0;
OneWire bus(D2);
DallasTemperature sensors(&bus);
NetworkClientSecure transport;
char eventId[32];
bool acknowledged = false;
uint32_t awakeStart;

void sleepNow() {
  esp_sleep_enable_timer_wakeup(uint64_t(ROOF_SLEEP_SECONDS) * 1000000ULL);
  esp_deep_sleep_start();
}

void deadlineTask(void *) {
  vTaskDelay(pdMS_TO_TICKS(AWAKE_LIMIT_MS));
  // Independent task bounds even a blocking network/library operation.
  sleepNow();
}


void setup() {
  awakeStart = millis();
  Serial.begin(115200);
  if (!sessionId) sessionId = esp_random();
  ++bootCount;
  const uint32_t lastStage = previousStage;
  ++failures; // Cleared only after the receiver commits and acknowledges this reading.
  previousStage = 1;
  snprintf(eventId, sizeof(eventId), "%08lx-%lu", (unsigned long)sessionId, (unsigned long)bootCount);
  if (xTaskCreate(deadlineTask, "awake-deadline", 3072, nullptr, 5, nullptr) != pdPASS) sleepNow();
  Serial.printf("WAKE %s reset=%d previous_stage=%lu\n", eventId, int(esp_reset_reason()), (unsigned long)lastStage);

  // Use the C6's built-in antenna.
  pinMode(3, OUTPUT); digitalWrite(3, LOW);
  pinMode(14, OUTPUT); digitalWrite(14, LOW);
  sensors.begin();
  DeviceAddress address;
  char rom[17] = "";
  float c = DEVICE_DISCONNECTED_C;
  bool sensorOk = sensors.getDeviceCount() == 1 && sensors.getAddress(address, 0) && address[0] == 0x28;
  if (sensorOk) {
    for (int i = 0; i < 8; ++i) snprintf(rom + i * 2, 3, "%02X", address[i]);
    sensors.setResolution(address, 12);
    sensors.setWaitForConversion(true);
    sensors.requestTemperatures();
    c = sensors.getTempC(address);
    sensorOk = isfinite(c) && c != DEVICE_DISCONNECTED_C && c >= -55 && c <= 125;
  }
  // 100k/100k divider with 100nF to GND: RC=5ms. Sample before radio load.
  uint32_t batterySumMv = 0;
  if (ROOF_BATTERY_SENSE) {
    pinMode(A0, INPUT);
    analogReadResolution(12);
    analogSetPinAttenuation(A0, ADC_11db);
    delay(50);
    analogReadMilliVolts(A0); // Discard initial conversion.
    for (int i = 0; i < 32; ++i) {
      delay(5);
      batterySumMv += analogReadMilliVolts(A0);
    }
  }
  const float batteryAdcMv = batterySumMv / 32.0f;
  const float batteryV = batteryAdcMv * 2.0f / 1000.0f;
  // Plausibility only, not state-of-charge or proof of wiring integrity.
  const bool batteryOk = ROOF_BATTERY_SENSE && batteryV >= 2.0f && batteryV <= 4.5f;
  char batteryText[24] = "null";
  if (batteryOk) snprintf(batteryText, sizeof(batteryText), "%.3f", batteryV);
  Serial.printf("Battery ADC=%.1f mV battery=%s V valid=%s\n",
                batteryAdcMv, batteryText, batteryOk ? "yes" : "no");
  previousStage = 2;
  WiFi.mode(WIFI_STA);
  WiFi.begin((ROOF_TEST_WIFI_FAILURE && bootCount == 1) ? "solar-sensor-failure-test-unavailable" : WIFI_SSID, WIFI_PASSWORD);
  while (WiFi.status() != WL_CONNECTED && millis() - awakeStart < 12000) delay(50);
  if (WiFi.status() != WL_CONNECTED) {
    Serial.printf("Wi-Fi unavailable; sleep at %lu ms\n", (unsigned long)(millis() - awakeStart));
    sleepNow();
  }
  previousStage = 3;
  // Match the established guest-network workaround: DHCP precedes usable DNS.
  delay(2500);
  // Guest Wi-Fi reaches the receiver through authenticated HTTPS.
  // NTP provides wall time for certificate validity checks.
  configTime(0, 0, "pool.ntp.org", "time.google.com");
  while (time(nullptr) < 1767225600 && millis() - awakeStart < 15000) delay(50);
  if (time(nullptr) < 1767225600) {
    Serial.println("Clock sync unavailable; sleeping without insecure TLS fallback");
    sleepNow();
  }
  transport.setCACert(ROOT_CA);
  transport.setHandshakeTimeout(4);
  transport.setConnectionTimeout(2500);
  HTTPClient http;
  http.setConnectTimeout(2500);
  http.setTimeout(3500);
  char tempC[24] = "null", tempF[24] = "null";
  if (sensorOk) {
    snprintf(tempC, sizeof(tempC), "%.4f", c);
    snprintf(tempF, sizeof(tempF), "%.4f", c * 1.8f + 32);
  }
  char payload[800];
  snprintf(payload, sizeof(payload),
    "{\"sensor\":\"roof-solar-reference\",\"event_id\":\"%s\",\"sensor_rom\":\"%s\","
    "\"temp_ok\":%s,\"temperature_c\":%s,\"temperature_f\":%s,"
    "\"battery_ok\":%s,\"battery_v\":%s,\"battery_adc_mv\":%.1f,"
    "\"wifi_rssi_dbm\":%d,\"boot_count\":%lu,\"reset_reason\":%d,\"sleep_seconds\":%u,"
    "\"previous_failures\":%lu,\"previous_stage\":%lu,\"previous_http_status\":%d,\"awake_before_publish_ms\":%lu}",
    eventId, rom, sensorOk ? "true" : "false", tempC, tempF,
    batteryOk ? "true" : "false", batteryText, batteryAdcMv, WiFi.RSSI(),
    (unsigned long)bootCount, int(esp_reset_reason()), ROOF_SLEEP_SECONDS,
    (unsigned long)(failures - 1), (unsigned long)lastStage, previousHttpStatus, (unsigned long)(millis() - awakeStart));
  previousStage = 4;
  int status = 0;
  const String url = (ROOF_TEST_HTTPS_FAILURE && bootCount == 2)
      ? String(INGEST_URL) + "/unavailable" : String(INGEST_URL);
  for (int attempt = 0; attempt < 2 && !acknowledged && millis() - awakeStart < 15000; ++attempt) {
    if (http.begin(transport, url)) {
      http.addHeader("Content-Type", "application/json");
      http.addHeader("Authorization", String("Bearer ") + INGEST_TOKEN);
      status = http.POST((uint8_t *)payload, strlen(payload));
      if (status == 200) acknowledged = http.getString() == eventId;
      http.end();
    }
    if (status >= 400 && status < 500) break;
    if (!acknowledged) delay(750);
  }
  previousHttpStatus = status;
  if (acknowledged) { failures = 0; previousStage = 0; }
  Serial.printf("Receiver stored=%s HTTP=%d temp=%s F RSSI=%d sleep=%u s awake=%lu ms\n",
                acknowledged ? "yes" : "no", status, tempF, WiFi.RSSI(), ROOF_SLEEP_SECONDS,
                (unsigned long)(millis() - awakeStart));
  sleepNow();
}
void loop() {}

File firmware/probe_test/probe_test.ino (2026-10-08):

// USB bench test: adapter VCC -> 3V3, GND -> GND, DAT -> D2.
// No Wi-Fi or deep sleep: keep serial available while checking the wiring.
#include <OneWire.h>
#include <DallasTemperature.h>
#include <math.h>

static_assert(D2 == 2, "Build for XIAO ESP32-C6 (D2 = GPIO2)");
OneWire bus(D2);
DallasTemperature sensors(&bus);
uint32_t sample = 0;

void setup() {
  Serial.begin(115200);
  delay(1500);
  Serial.println("XIAO ESP32-C6 probe test: D2/GPIO2, powered 3-wire DS18B20");
}

void loop() {
  // Re-scan so an unplugged/reconnected probe recovers without a reset.
  sensors.begin();
  DeviceAddress address;
  ++sample;
  if (sensors.getDeviceCount() != 1 || !sensors.getAddress(address, 0) || address[0] != 0x28) {
    Serial.printf("{\"sample\":%lu,\"temp_ok\":false,\"error\":\"expected_one_ds18b20\",\"devices\":%u}\n",
                  (unsigned long)sample, sensors.getDeviceCount());
  } else {
    sensors.setResolution(address, 12);
    sensors.setWaitForConversion(true);
    sensors.requestTemperatures();
    const float c = sensors.getTempC(address); // Library verifies scratchpad CRC.
    const bool ok = isfinite(c) && c != DEVICE_DISCONNECTED_C && c >= -55 && c <= 125;
    Serial.printf("{\"sample\":%lu,\"sensor_rom\":\"", (unsigned long)sample);
    for (uint8_t b : address) Serial.printf("%02X", b);
    if (ok) {
      Serial.printf("\",\"temp_ok\":true,\"temperature_c\":%.4f,\"temperature_f\":%.4f}\n", c, c * 1.8f + 32);
    } else {
      Serial.println("\",\"temp_ok\":false,\"error\":\"conversion_or_read_failed\"}");
    }
  }
  delay(1250);
}

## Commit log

2026-08-31 Add roof sensor design doc and step-by-step build guide
    Design spec for the solar-powered Wi-Fi roof temperature node
    (XIAO ESP32-C3 + DFR0559 + DS18B20), plus a self-contained HTML
    build guide covering firmware, breadboard bring-up, the perfboard
    sled, enclosure work, and roof installation.
    Claude-Session: https://claude.ai/code/session_01JMDqoX4bNHLbPyA1HjdnX3
2026-10-08 Publish reproducible C6 build, receiver and current enclosure
    [arm.step, arm.stl, assembly-reference.step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]
2026-10-22 Add USB water sensor and persistent diagnostics for both sensors
